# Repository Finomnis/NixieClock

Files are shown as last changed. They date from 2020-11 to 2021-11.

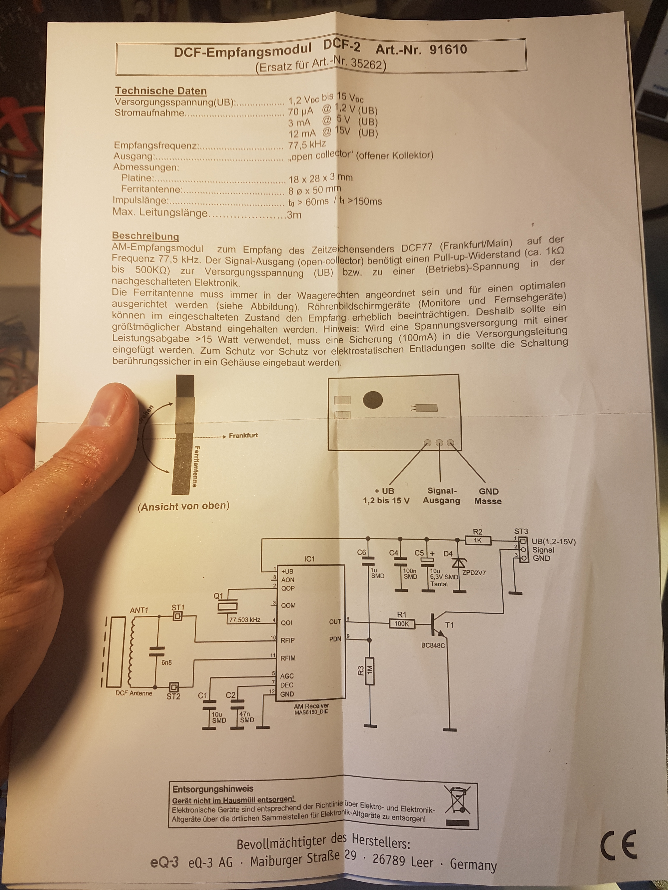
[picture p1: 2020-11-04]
Docs/DCF2/DCF2_1.jpg

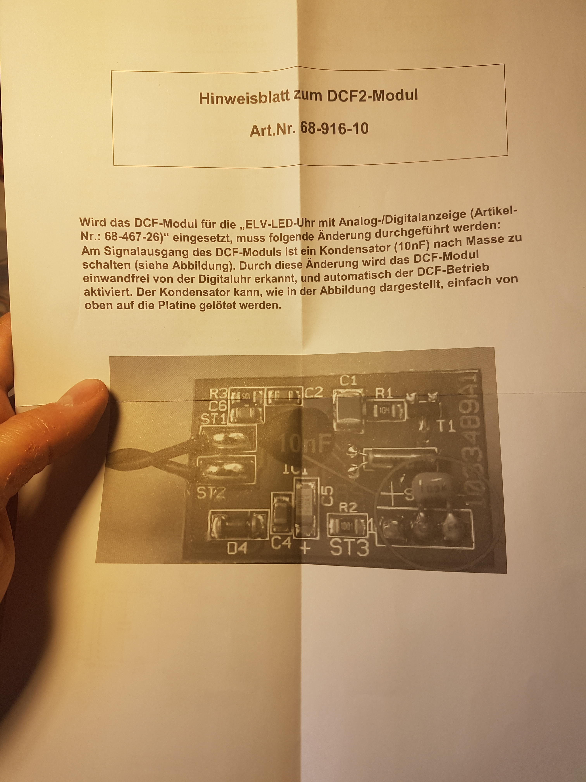
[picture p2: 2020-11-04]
Docs/DCF2/DCF2_2.jpg

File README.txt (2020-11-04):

Repository structure follows
https://medium.com/inventhub/better-manage-kicad-projects-using-git-8d06e1310af8

Hardware — contains the KiCAD Project, Schematics & Layout and Project Libraries
Firmware — contains any software developed for the Hardware
Docs — contains any data sheets or documentations
Production — contains the gerber files, BOM or anything required by the fabrication houses
Simulation — contains any simulation files and generated results
CAD — contains the 3D models and mechanical designs for enclosures or support

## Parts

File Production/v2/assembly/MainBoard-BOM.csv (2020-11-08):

Designator | Quantity | Value | Footprint | LCSC Part #
C1, C2, C3, C7, | 4 | 100n | 0603 | C14663
C6, | 1 | 330n | 0603 | C1615
C8, | 1 | 10u | 0805 | C15850
F2, | 1 | 200mA | 0603 | C207010
Q1, | 1 | S8050 | SOT-23-3 | C2146
R1, R2, R3, R4, | 4 | 10k | 1206 | C17902
R5, | 1 | 470 | 0603 | C23179
R6, R8, | 2 | 10k | 0603 | C25804
R7, R9, | 2 | 100k | 0603 | C25803
R10, | 1 | 100k | 1206 | C17900
U4, | 1 | L78M05ABDT-TR | TO-252-2 | C58069

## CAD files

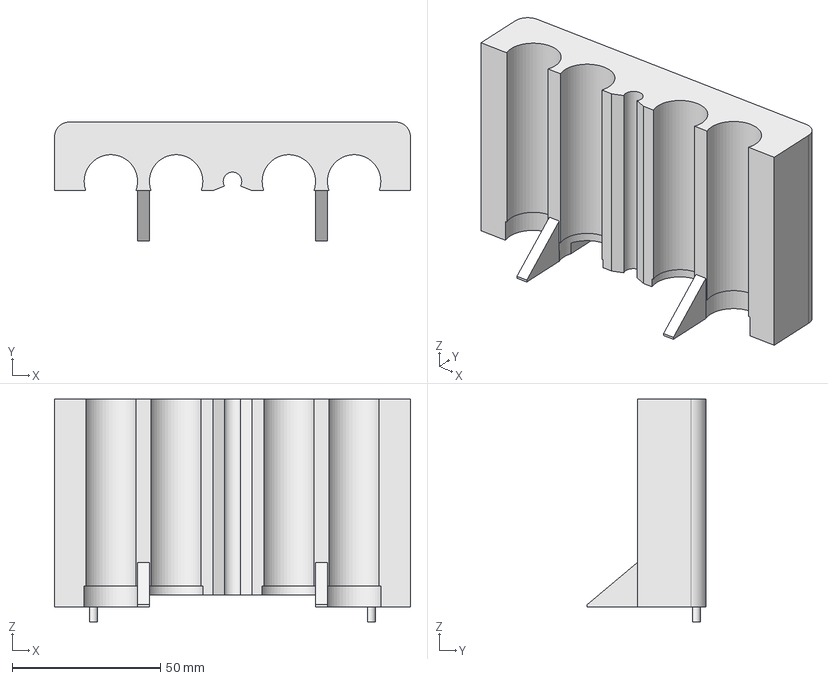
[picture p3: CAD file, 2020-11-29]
Utilities/NixieAlignmentHelper.FCStd
120.0 x 40.1 x 75.0 mm

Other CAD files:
Utilities/NixieAlignmentHelper.stl

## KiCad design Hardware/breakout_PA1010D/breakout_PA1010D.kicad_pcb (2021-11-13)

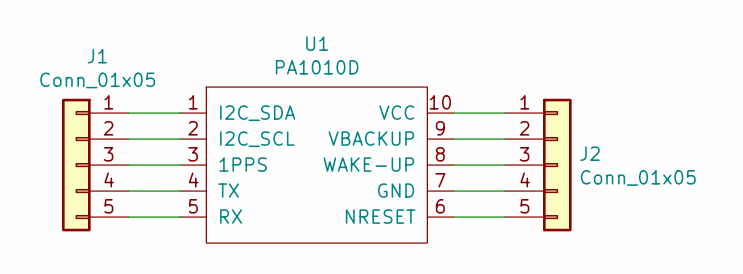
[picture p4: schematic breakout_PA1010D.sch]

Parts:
J1, J2: Conn_01x05; PinHeader_1x05_P2.54mm_Vertical
U1: PA1010D

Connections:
unnamed: J1.1, U1.1 (I2C_SDA)
unnamed: J1.2, U1.2 (I2C_SCL)
unnamed: J1.3, U1.3 (1PPS)
unnamed: J1.4, U1.4 (TX)
unnamed: J1.5, U1.5 (RX)
unnamed: J2.1, U1.10 (VCC)
unnamed: J2.2, U1.9 (VBACKUP)
unnamed: J2.3, U1.8 (WAKE-UP)
unnamed: J2.4, U1.7 (GND)
unnamed: J2.5, U1.6 (NRESET)

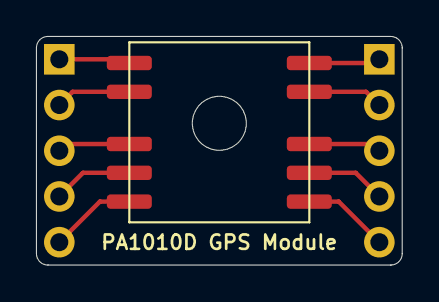
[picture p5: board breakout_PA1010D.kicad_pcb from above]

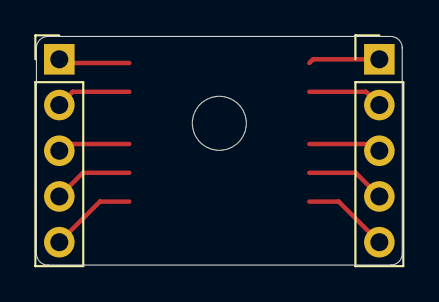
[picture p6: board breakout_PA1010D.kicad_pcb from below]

Board: 2 copper layers, 20.3 x 12.7 mm, 3 parts (2 on the bottom side), 10 nets.

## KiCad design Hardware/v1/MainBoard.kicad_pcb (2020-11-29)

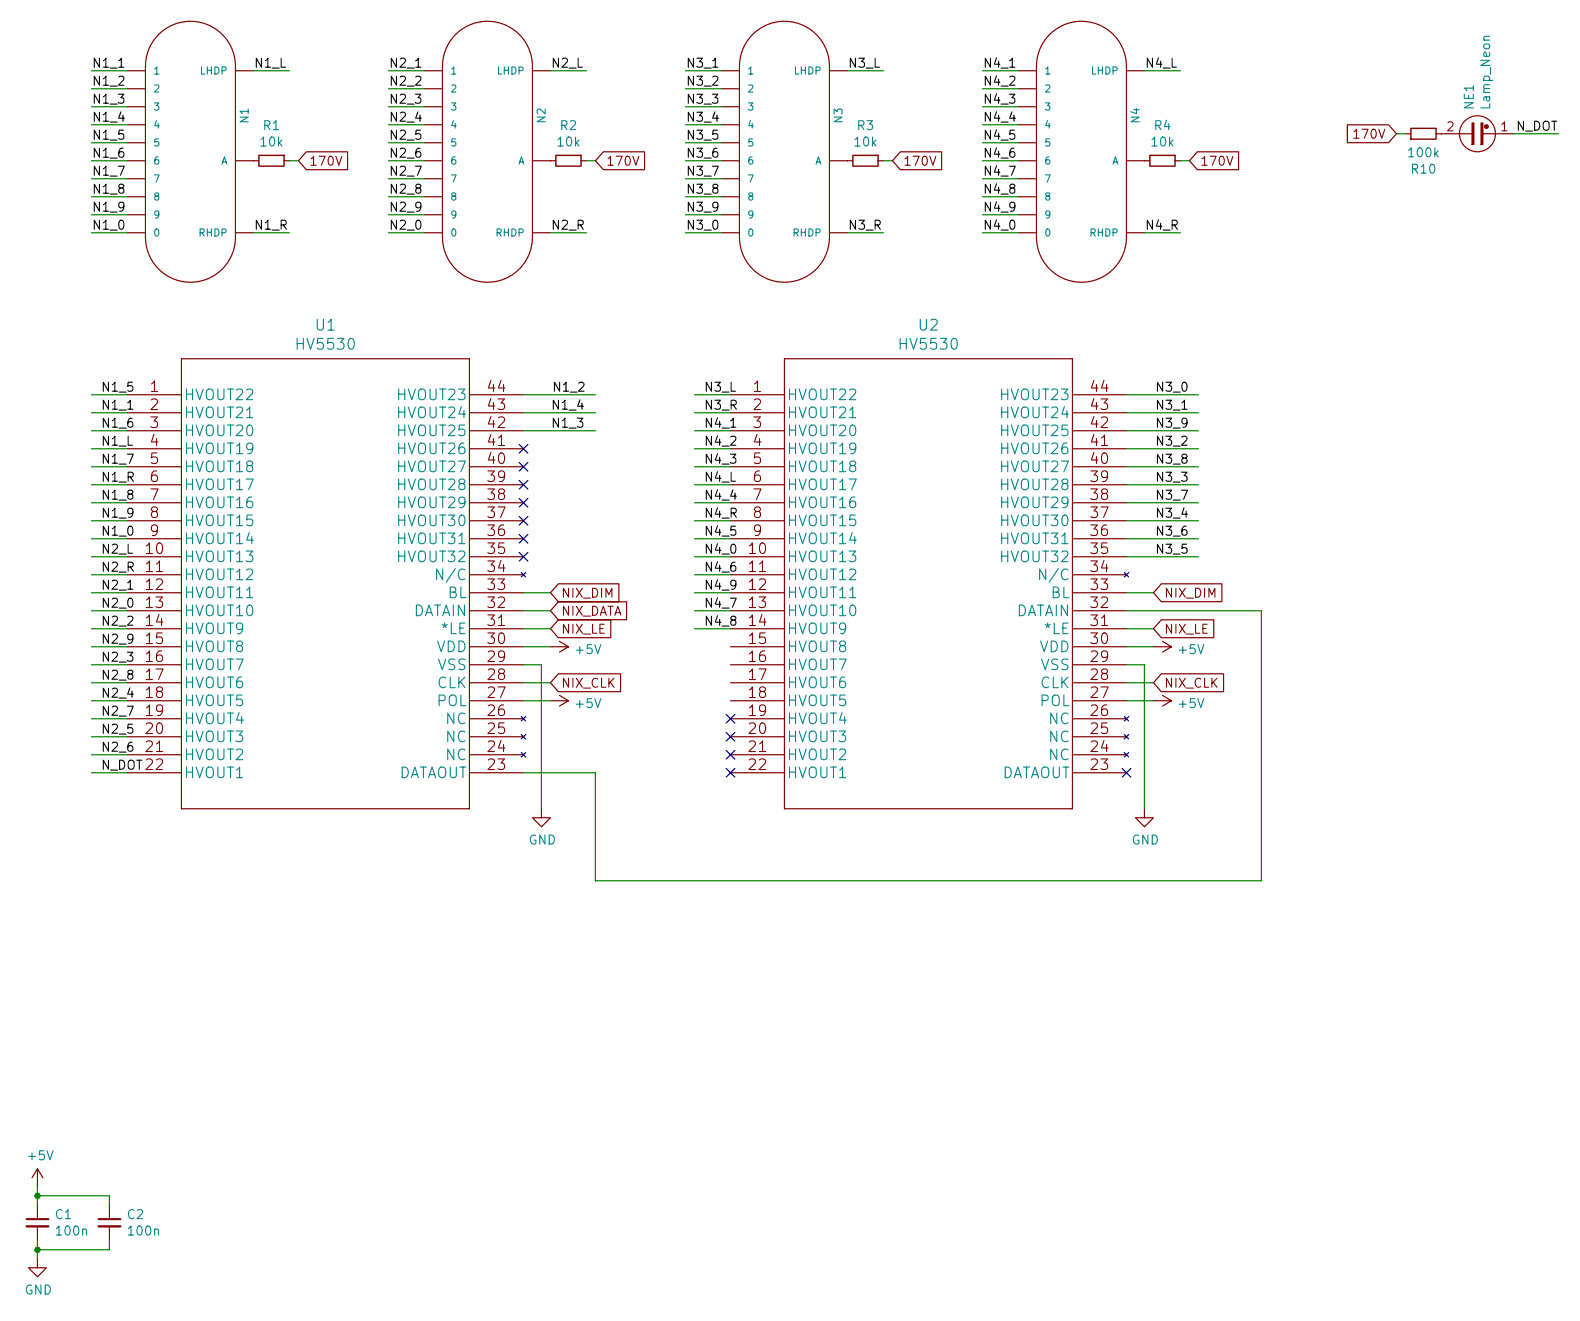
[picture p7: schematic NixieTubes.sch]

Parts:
C1, C2: 100n; C_0603_1608Metric
N1, N2, N3, N4: IN-14
NE1: Lamp_Neon; Colon
R1, R2, R3, R4: 10k; R_1206_3216Metric
R10: 100k; R_1206_3216Metric
U1, U2: HV5530; PQFP-44_10x10mm_P0.8mm

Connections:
170V: R1.1, R2.1, R3.1, R4.1, R10.1; also elsewhere on the board
+5V: C1.1, C2.1, U1.27 (POL), U1.30 (VDD), U2.27 (POL), U2.30 (VDD); also elsewhere on the board
/NixieTubes/N1_0: N1.0, U1.9 (HVOUT14)
/NixieTubes/N1_1: N1.1, U1.2 (HVOUT21)
/NixieTubes/N1_2: N1.2, U1.44 (HVOUT23)
/NixieTubes/N1_3: N1.3, U1.42 (HVOUT25)
/NixieTubes/N1_4: N1.4, U1.43 (HVOUT24)
/NixieTubes/N1_5: N1.5, U1.1 (HVOUT22)
/NixieTubes/N1_6: N1.6, U1.3 (HVOUT20)
/NixieTubes/N1_7: N1.7, U1.5 (HVOUT18)
/NixieTubes/N1_8: N1.8, U1.7 (HVOUT16)
/NixieTubes/N1_9: N1.9, U1.8 (HVOUT15)
/NixieTubes/N1_L: N1.LHDP, U1.4 (HVOUT19)
/NixieTubes/N1_R: N1.RHDP, U1.6 (HVOUT17)
/NixieTubes/N2_0: N2.0, U1.13 (HVOUT10)
/NixieTubes/N2_1: N2.1, U1.12 (HVOUT11)
/NixieTubes/N2_2: N2.2, U1.14 (HVOUT9)
/NixieTubes/N2_3: N2.3, U1.16 (HVOUT7)
/NixieTubes/N2_4: N2.4, U1.18 (HVOUT5)
/NixieTubes/N2_5: N2.5, U1.20 (HVOUT3)
/NixieTubes/N2_6: N2.6, U1.21 (HVOUT2)
/NixieTubes/N2_7: N2.7, U1.19 (HVOUT4)
/NixieTubes/N2_8: N2.8, U1.17 (HVOUT6)
/NixieTubes/N2_9: N2.9, U1.15 (HVOUT8)
/NixieTubes/N2_L: N2.LHDP, U1.10 (HVOUT13)
/NixieTubes/N2_R: N2.RHDP, U1.11 (HVOUT12)
/NixieTubes/N3_0: N3.0, U2.44 (HVOUT23)
/NixieTubes/N3_1: N3.1, U2.43 (HVOUT24)
/NixieTubes/N3_2: N3.2, U2.41 (HVOUT26)
/NixieTubes/N3_3: N3.3, U2.39 (HVOUT28)
/NixieTubes/N3_4: N3.4, U2.37 (HVOUT30)
/NixieTubes/N3_5: N3.5, U2.35 (HVOUT32)
/NixieTubes/N3_6: N3.6, U2.36 (HVOUT31)
/NixieTubes/N3_7: N3.7, U2.38 (HVOUT29)
/NixieTubes/N3_8: N3.8, U2.40 (HVOUT27)
/NixieTubes/N3_9: N3.9, U2.42 (HVOUT25)
/NixieTubes/N3_L: N3.LHDP, U2.1 (HVOUT22)
/NixieTubes/N3_R: N3.RHDP, U2.2 (HVOUT21)
/NixieTubes/N4_0: N4.0, U2.10 (HVOUT13)
/NixieTubes/N4_1: N4.1, U2.3 (HVOUT20)
/NixieTubes/N4_2: N4.2, U2.4 (HVOUT19)
/NixieTubes/N4_3: N4.3, U2.5 (HVOUT18)
/NixieTubes/N4_4: N4.4, U2.7 (HVOUT16)
/NixieTubes/N4_5: N4.5, U2.9 (HVOUT14)
/NixieTubes/N4_6: N4.6, U2.11 (HVOUT12)
/NixieTubes/N4_7: N4.7, U2.13 (HVOUT10)
/NixieTubes/N4_8: N4.8, U2.14 (HVOUT9)
/NixieTubes/N4_9: N4.9, U2.12 (HVOUT11)
/NixieTubes/N4_L: N4.LHDP, U2.6 (HVOUT17)
/NixieTubes/N4_R: N4.RHDP, U2.8 (HVOUT15)
/NixieTubes/N_DOT: NE1.1, U1.22 (HVOUT1)
GND: C1.2, C2.2, U1.29 (VSS), U2.29 (VSS); also elsewhere on the board
NIX_CLK: U1.28 (CLK), U2.28 (CLK); also elsewhere on the board
NIX_DATA: U1.32 (DATAIN); also elsewhere on the board
NIX_DIM: U1.33 (BL), U2.33 (BL); also elsewhere on the board
NIX_LE: U1.31 (*LE), U2.31 (*LE); also elsewhere on the board
unnamed: N1.A, R1.2
unnamed: N2.A, R2.2
unnamed: N3.A, R3.2
unnamed: N4.A, R4.2
unnamed: NE1.2, R10.2
unnamed: U1.23 (DATAOUT), U2.32 (DATAIN)

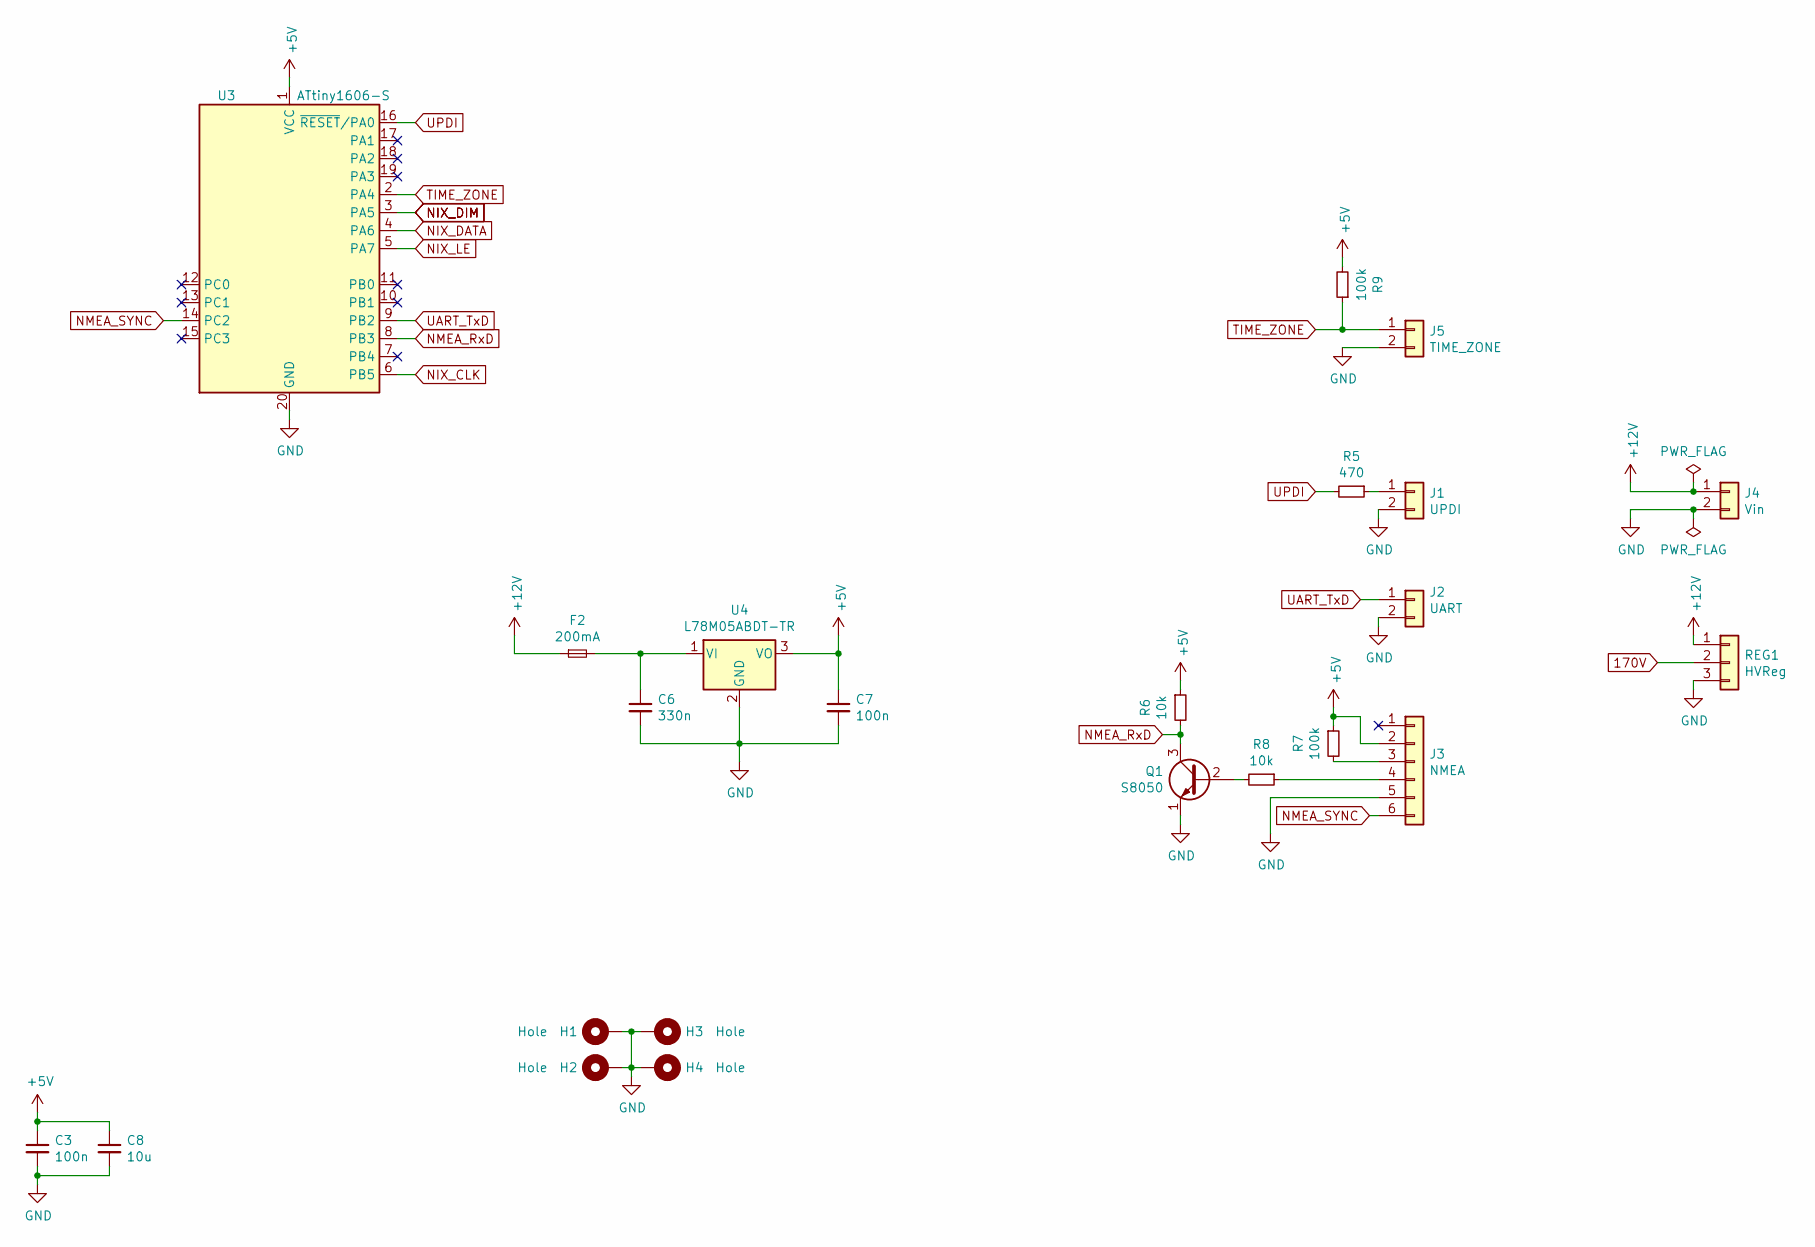
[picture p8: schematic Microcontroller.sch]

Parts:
C3, C7: 100n; C_0603_1608Metric
C6: 330n; C_0603_1608Metric
C8: 10u; C_0805_2012Metric
F2: 200mA; Fuse_0603_1608Metric
H1, H2, H3, H4: Hole; MountingHole_2.7mm_M2.5_Pad_Via
J1: UPDI; PinHeader_1x02_P2.54mm_Vertical
J2: UART; PinHeader_1x02_P2.54mm_Vertical
J3: NMEA; PinHeader_1x06_P1.27mm_Vertical
J4: Vin; PinHeader_1x02_P2.54mm_Vertical
J5: TIME_ZONE; PinHeader_1x02_P2.54mm_Vertical
Q1: S8050; SOT-23
R5: 470; R_0603_1608Metric
R6, R8: 10k; R_0603_1608Metric
R7, R9: 100k; R_0603_1608Metric
REG1: HVReg; NCH8200HV
U3: ATtiny1606-S; SOIC-20W_7.5x12.8mm_P1.27mm
U4: L78M05ABDT-TR; TO-252-2

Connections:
170V: REG1.2; also elsewhere on the board
+5V: C3.1, C7.1, C8.1, J3.2, R6.1, R7.1, R9.2, U3.1 (VCC), U4.3 (VO); also elsewhere on the board
+12V: F2.1, J4.1, REG1.1
GND: C3.2, C6.2, C7.2, C8.2, H1.1, H2.1, H3.1, H4.1, J1.2, J2.2, J3.5, J4.2, J5.2, Q1.1 (E), REG1.3, U3.20 (GND), U4.2 (GND); also elsewhere on the board
NIX_CLK: U3.6 (PB5); also elsewhere on the board
NIX_DATA: U3.4 (PA6); also elsewhere on the board
NIX_DIM: U3.3 (PA5); also elsewhere on the board
NIX_LE: U3.5 (PA7); also elsewhere on the board
NMEA_RxD: Q1.3 (C), R6.2, U3.8 (PB3)
NMEA_SYNC: J3.6, U3.14 (PC2)
unnamed: C6.1, F2.2, U4.1 (VI)
unnamed: J1.1, R5.1
unnamed: J3.3, R7.2
unnamed: J3.4, R8.1
unnamed: Q1.2 (B), R8.2
TIME_ZONE: J5.1, R9.1, U3.2 (PA4)
UART_TxD: J2.1, U3.9 (PB2)
UPDI: R5.2, U3.16 (~RESET~/PA0)

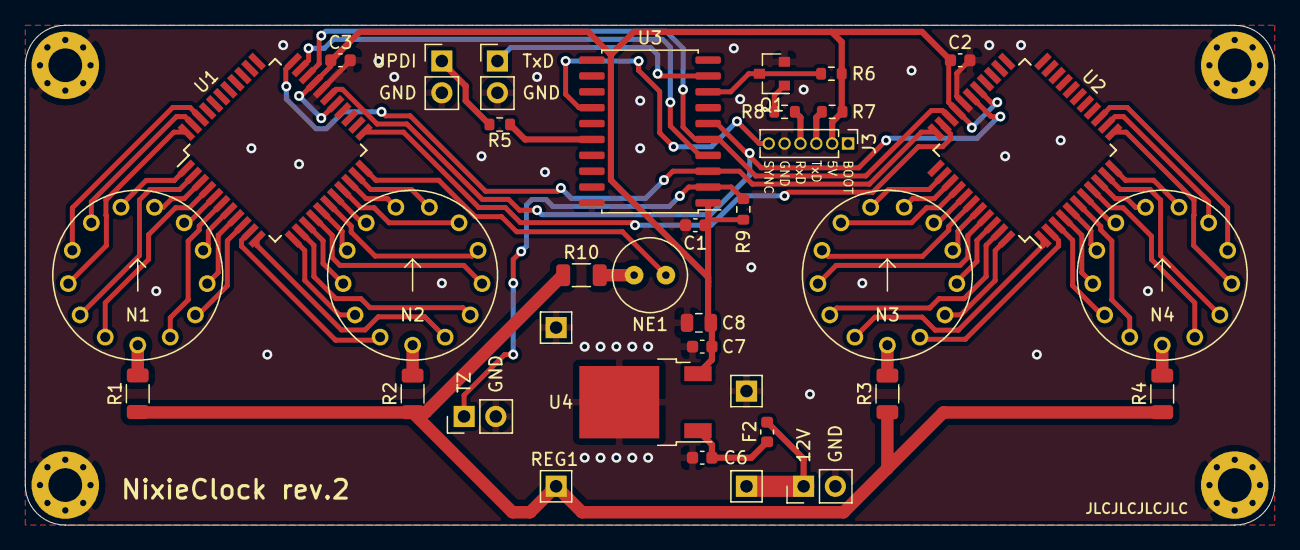
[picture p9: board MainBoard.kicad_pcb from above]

Board: 2 copper layers, 100.0 x 40.0 mm, 37 parts (0 on the bottom side), 73 nets.

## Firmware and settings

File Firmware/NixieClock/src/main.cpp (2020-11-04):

#include <Arduino.h>

#include "Pins.h"
#include "NixieDisplay.h"
#include "SineAnimation.h"
#include "Settings.h"
#include "DimAnimation.h"
#include "Nmea.h"

void setup()
{
    Serial.begin(9600);
    PINS.initializePins();
    NixieDisplay.init();
    Nmea.init();
}

void updateNmea()
{
    Nmea.update();
}

void updateDisplay()
{
    // Numbers
    NixieDisplay.setNumbers(Nmea.getHoursMsd(),
                            Nmea.getHoursLsd(),
                            Nmea.getMinutesMsd(),
                            Nmea.getMinutesLsd());

    // Colon
    NixieDisplay.setColon(Nmea.isInitialized());

    // Dots
    if (Nmea.isInitialized() && !Nmea.isOutdated())
    {
        SineAnimation.setActive(false);
        NixieDisplay.clearDots();
    }
    else
    {
        // If freshly initialized or not synced for a while, show resync bar
        SineAnimation.setActive(true);
        SineAnimation.update();
    }

    // Dim
    if (Settings.DISPLAY_DIM_AT_NIGHT)
    {
        static bool currentlyDimmed = false;

        uint16_t dayMinutes = Nmea.getMinutes() + 60L * Nmea.getHours();
        bool shouldBeDimmed = Nmea.isInitialized() &&
                              ((Settings.DISPLAY_DIM_START < Settings.DISPLAY_DIM_END)
                                   ? (dayMinutes >= Settings.DISPLAY_DIM_START && dayMinutes < Settings.DISPLAY_DIM_END)
                                   : (dayMinutes >= Settings.DISPLAY_DIM_START || dayMinutes < Settings.DISPLAY_DIM_END));

        if (shouldBeDimmed != currentlyDimmed)
        {
            // Don't do anything for the first 5 seconds of the minute, as this could get interrupted by the dcf update
            if (Nmea.getSeconds() > 5)
            {
                currentlyDimmed = shouldBeDimmed;
                if (shouldBeDimmed)
                {
                    DimAnimation.start(255, Settings.DISPLAY_DIM_BRIGHTNESS, Settings.DISPLAY_DIM_ANIMATION_DURATION);
                }
                else
                {
                    DimAnimation.start(Settings.DISPLAY_DIM_BRIGHTNESS, 255, Settings.DISPLAY_DIM_ANIMATION_DURATION);
                }
            }
        }
        else
        {
            if (DimAnimation.isRunning())
            {
                DimAnimation.render();
            }
            else
            {
                NixieDisplay.setBrightness(shouldBeDimmed ? Settings.DISPLAY_DIM_BRIGHTNESS : 255);
            }
        }
    }
    else
    {
        NixieDisplay.setBrightness(255);
    }

    NixieDisplay.flush();
}

void loop()
{
    updateNmea();
    updateDisplay();
}

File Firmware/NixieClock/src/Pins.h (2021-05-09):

#pragma once

#include <Arduino.h>

struct PINS_t
{
    const uint8_t NIXIE_DIM = PIN_PA5;
    const uint8_t NIXIE_DATA = PIN_PA6;
    const uint8_t NIXIE_LATCH = PIN_PA7;
    const uint8_t NIXIE_CLK = PIN_PB5;

    const uint8_t TIME_ZONE = PIN_PA4;
    const uint8_t NMEA_SYNC = PIN_PC2;

    void initializePins() const
    {
        pinMode(NIXIE_DIM, OUTPUT);
        pinMode(NIXIE_DATA, OUTPUT);
        pinMode(NIXIE_LATCH, OUTPUT);
        pinMode(NIXIE_CLK, OUTPUT);
        pinMode(TIME_ZONE, INPUT);
        pinMode(NMEA_SYNC, INPUT);

        // Set PWM frequency
        constexpr int TCA = 0x0A00;
        *((char *)TCA) = 0b00001111;
    }
};

extern const PINS_t PINS;

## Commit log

2020-10-01 DCF Filtering
2020-10-01 Refined dcf filtering
2020-10-02 Reworked RealTimeClock to be interrupt compatible
    [main.cpp]
2020-10-02 Fixed blink duration during update was too short
    [main.cpp]
2020-10-02 Add missing pins, fixes too high energy consumption due to floating wires
2020-10-05 Fix nixies getting dimmed during initial sync
    [main.cpp]
2020-10-06 Disable resync indicator, as sync doesn't work reliable enough, and clock accuracy is already fine without resync
    [main.cpp]
2020-11-03 Switched time source to NMEA GPS
2020-11-04 First Hardware commit
    [MainBoard.kicad_pcb, MainBoard.sch, Microcontroller.sch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]
2020-11-04 Fix library paths
    [MainBoard.kicad_pcb]
2020-11-04 Reworked Schematic for GPS
    [Microcontroller.sch]
2020-11-06 Start rework
    [MainBoard.kicad_pcb, Microcontroller.sch, NixieTubes.sch]
2020-11-06 Add signal inversion for NMEA
    [Microcontroller.sch]
2020-11-06 Fix packages, route left nixies
    [MainBoard.kicad_pcb, Microcontroller.sch, NixieTubes.sch]
2020-11-06 More layouting
    [MainBoard.kicad_pcb, Microcontroller.sch]
2020-11-08 Replace LDO
    [MainBoard.kicad_pcb, Microcontroller.sch, NixieTubes.sch]
2020-11-08 Route UPDI and UART
    [MainBoard.kicad_pcb, Microcontroller.sch]
2020-11-08 Routed right nixies
    [MainBoard.kicad_pcb, NixieTubes.sch]
2020-11-08 Finish routing connections
    [MainBoard.kicad_pcb]
2020-11-08 Add ground vias
    [MainBoard.kicad_pcb]
2020-11-08 Minor fixes to ground plane
    [MainBoard.kicad_pcb]
2020-11-08 Change mounting holes to M2.5
    [MainBoard.kicad_pcb, Microcontroller.sch]
2020-11-08 Add timezone switch
    [MainBoard.kicad_pcb, Microcontroller.sch]
2020-11-08 Moved NMEA connector further to the back
    [MainBoard.kicad_pcb]
2020-11-08 Silk screen fixes
    [MainBoard.kicad_pcb]
2020-11-08 Fix another silkscreen
    [MainBoard.kicad_pcb]
2020-11-08 Production: v2
    [MainBoard-BOM.csv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]
2020-11-08 Add forgotten file. Still belongs to v2
    [Microcontroller.sch]
2020-11-17 Fix shift register polarities
    [NixieDisplay.cpp]
2020-11-22 Add Nixie Alignment Helper
    [NixieAlignmentHelper.FCStd, NixieAlignmentHelper.stl]
2020-11-29 Fix Q1 pinout
    [MainBoard.kicad_pcb]
2020-11-29 Add verification measurements to NixieAlignmentHelper
    [NixieAlignmentHelper.FCStd]
2020-12-28 Update pins for new board
2020-12-28 Fix pin mappings in NixieDisplay.cpp
    [NixieDisplay.cpp]
2020-12-28 fix pins.h name, part2
    [Pins.h]
2020-12-28 Add timezone switch to Nmea.cpp
2021-02-04 Reduce pwm frequency to minimize feeping noise
    [Pins.h]
2021-05-09 Add flash instructions, adjust PWM frequency
2021-08-15 Change firmware framework to platformio
2021-11-13 Move Hardware to Hardware/v1
    [MainBoard.kicad_pcb, MainBoard.sch, Microcontroller.sch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]
2021-11-13 Add PA1010D breakout board
    [breakout_PA1010D.kicad_pcb, breakout_PA1010D.sch]
2021-11-13 Fix minor text issue in PA1010D footprint
    [breakout_PA1010D.kicad_pcb]
2021-11-13 Fix forgotten save
    [breakout_PA1010D.kicad_pcb, breakout_PA1010D.sch]
